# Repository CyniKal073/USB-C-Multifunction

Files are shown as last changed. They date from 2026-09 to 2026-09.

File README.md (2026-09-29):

# USB-C Multifunction

一款面向消费电子的 **USB Type-C 多功能扩展设备**：在单根 Type-C 连接下同时实现 USB 扩展、PD 快充透传、USB Audio 与外设线控交互，解决移动设备取消 3.5mm 耳机孔后「边充电边使用有线耳机」的问题。

> *A USB Type-C multifunction dock featuring USB 2.0 hub expansion, PD pass-through charging, a built-in USB audio codec, and MCU-based headset remote emulation.*

本项目为个人独立完成的完整硬件项目，涵盖系统方案设计与器件选型、4 层 PCB 设计、外壳结构设计与裸机固件开发。

设计初衷很直接：让那些喜欢同时插着一堆外设的人，可以边充电边用。

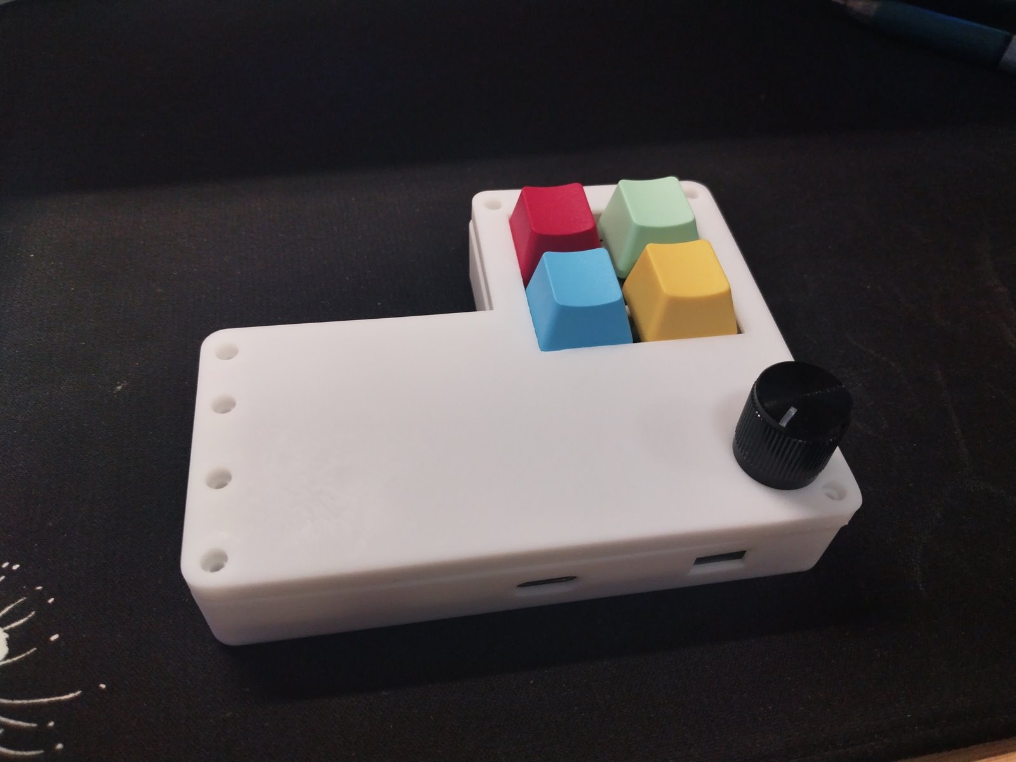
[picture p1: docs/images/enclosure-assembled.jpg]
成品实物


*成品外观：4 个可编程按键 + EC11 旋钮，外壳为自建 3D 模型打印件。*

---

## 目录

- [功能特性](#功能特性)
- [系统架构](#系统架构)
- [实测指标](#实测指标)
- [硬件设计](#硬件设计)
- [结构设计](#结构设计)
- [设计演进与实物](#设计演进与实物)
- [固件](#固件)
- [仓库结构](#仓库结构)
- [待办与已知问题](#待办与已知问题)
- [致谢与许可](#致谢与许可)

---

## 功能特性

| 功能 | 说明 |
| --- | --- |
| **USB 扩展** | 基于 CH334P 四口 USB 2.0 Hub，下行提供 2× USB-A 与 2× Type-C 接口，支持 480Mbps 高速模式 |
| **PD 快充透传** | 由 MCU 完成 Type-C CC 检测与 PD Sink 逻辑，扣除板载约 5W 供电后，最大可透传 95W 快充 |
| **USB Audio** | 板载 ATE700Q 音频编解码芯片，支持 44.1kHz / 96kHz 采样，可直接驱动 16–32Ω 耳机 |
| **线控交互** | 通过模拟开关与 MCU 时序控制模拟 CTIA 标准线控协议，以阻抗脉冲方式注入按键事件，扩展声卡线控功能 |
| **正反插识别** | Type-C CC 检测实现设备端正反插识别，并动态切换外围信号通道 |
| **可编程控制** | 4 个可编程按键与 EC11 旋转编码器，由 CH32X035F8U6 裸机固件驱动，实现 USB HID 复合设备与事件管理 |

## 系统架构

```mermaid
flowchart LR
    HOST["手机 / 主机<br/>Type-C 上行"] --> HUB["CH334P<br/>USB 2.0 Hub<br/>480Mbps<br/>CH227P"]
    HUB --> A["2× USB-A"]
    HUB --> C["2× Type-C"]
    HUB --> CODEC["ATE700Q<br/>USB Audio Codec"]
    CODEC --> JACK["3.5mm 耳机座 CN1"]
    MCU["CH32X035F8U6<br/>RISC-V MCU"] --> SW["TS3A5017<br/>模拟开关"]
    SW --> JACK
    MCU --> ENC["EC11 旋转编码器"]
    MCU --> KEY["按键矩阵"]
    MCU --> CC["Type-C CC 检测 / PD Sink"]
```

> 上图为简化示意，完整连接关系以 [`hardware/schematic`](hardware/schematic) 中的原理图为准。

## 实测指标

| 项目 | 结果 |
| --- | --- |
| USB 集线器速率 | 480Mbps 高速模式 |
| 快充功率 | 扣除板载约 5W 供电后，设计最大透传 95W |
| PD 实测 | 用 20W 充电器验证 PD 透传通路：协议 PD3.0 握手成功，协商到 15W 档位（12V / 1.25A），实测 14.12W |
| 音频采样率 | 44.1kHz / 96kHz |
| 耳机驱动能力 | 16–32Ω |

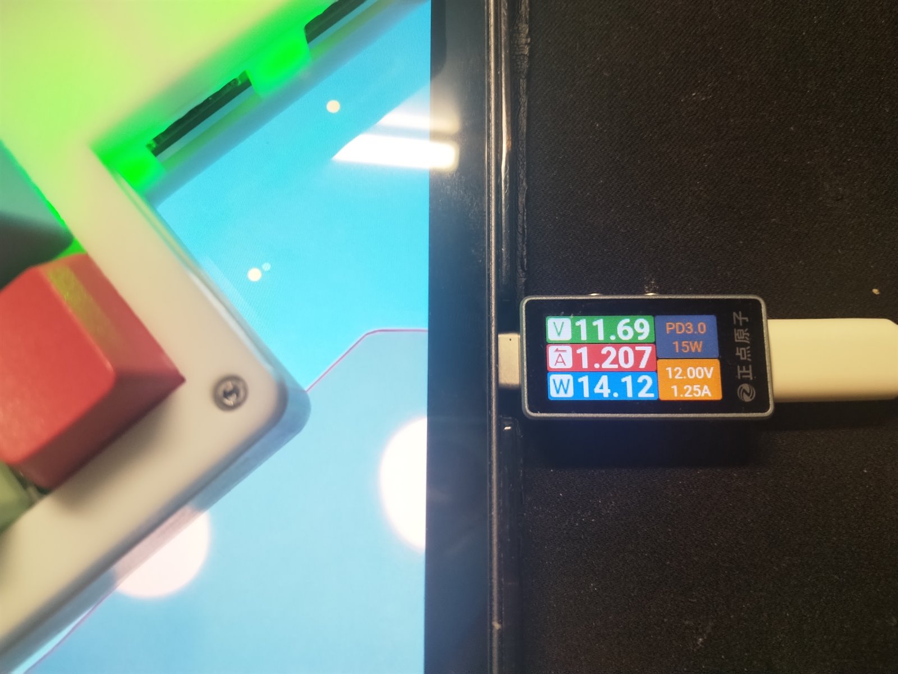
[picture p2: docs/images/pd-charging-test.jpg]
PD 快充实测


*以平板为受电端的 PD 实测：协议 PD3.0，电压 11.69V、电流 1.207A，功率 14.12W。这里之所以只看到 15W 档，是因为手上的充电器最大输出只有 20W——该测试的目的不是验证功率上限，而是确认板上约 5W 的自耗确实是从透传功率里扣除的。*

## 硬件设计

4 层板设计，重点处理 USB 2.0 差分信号阻抗与等长、电源平面规划以及高速信号回流路径；针对 USB、电源与模拟音频接口分别设计 ESD 防护与可靠性措施。

### 核心器件

| 位号 | 型号 | 厂商 | 作用 |
| --- | --- | --- | --- |
| U1 | CH32X035F8U6 | 南京沁恒 (WCH) | 主控 MCU，RISC-V 内核，负责 CC 检测、线控时序与 HID 通信 |
| U2 | CH334P | 南京沁恒 (WCH) | USB 2.0 四口 Hub 控制器 |
| U10 | CH227P | 南京沁恒 (WCH) | PD 快充协议芯片，与 CH334P 共同构成 HUB + PD 方案 |
| U29 | ATE700Q | — | USB 音频编解码（板载声卡） |
| U36 | TS3A5017DR | TI | 4:1 模拟开关，用于线控阻抗脉冲注入 |
| U11 / U35 | CH443K | 南京沁恒 (WCH) | 模拟开关，用于外围信号通道切换 |
| SW5 | EC11E15244G1 | ALPSALPINE | 旋转编码器（带按压） |
| CN1 | ST-0337D00-071-1A2H | G-Switch | 3.5mm 音频座 |
| D2/D7/D11/D13 | USBLC6-2SC6 | ST | USB 差分线 ESD 防护 |
| D10/D14/D15/D16 | RClamp0524PATCT | SEMTECH | 高速信号 ESD 防护 |

整个方案围绕 CH334P + CH227P 展开，供电通路同时做过流、过压与静电防护。

- **可编辑工程**：立创EDA 专业版（EasyEDA Pro）的原理图与 PCB 工程文件见 [`hardware/eda`](hardware/eda)，导入后可直接修改。
- **物料清单**：见 [`hardware/bom`](hardware/bom)，含原版 xlsx 与文本版 `BOM_*_2026-09-30.tsv`（UTF-8、Tab 分隔——位号列本身含逗号，用 Tab 分隔可以避免转义问题），文本版便于在 GitHub 上直接预览表格以及做版本对比。

### 制板与焊接注意事项

- 线对板针座（卧贴封装）的原始焊盘偏小，手工焊接时容易连锡。打板前建议手动把这两个焊盘向外加大，可明显降低焊接难度。

## 结构设计

`mechanical/` 下为 EasyEDA Pro 导出的外壳 3D 模型（ASCII STL），上下盖按装配位置导出：

| 文件 | 部件 | Z 范围 |
| --- | --- | --- |
| `enclosure-bottom.stl` | 下盖 | 0 – 15mm |
| `enclosure-top.stl` | 上盖 | 15 – 20mm |

整体外形尺寸约 **103.8 × 84.7 × 20mm**。

## 设计演进与实物

最终方案不是一次成型的。从选型验证到集成，前后经历了几个阶段，各阶段的原理图与制板文件都保留在 [`hardware/legacy`](hardware/legacy) 下，实物照片放在 [`docs/images`](docs/images)。

| 阶段 | 内容 | 记录位置 |
| --- | --- | --- |
| ① 声卡方案验证 | 基于 HS-100B 的 USB 声卡，含外壳 | `hardware/legacy/usb-soundcard-hs100b/` |
| ② 声卡方案更换 | 改用 ATE700Q，体积大幅缩小 | `hardware/legacy/usb-soundcard-ate700q/` |
| ③ 主体功能验证 | 4 口 HUB + PD 快充主板（原理图 v1） | `hardware/legacy/hub-v1/` |
| ④ 系统集成 | HUB + PD + 声卡 + MCU 线控合成单板 | 本仓库 `hardware/` `mechanical/` `firmware/` |

### 实物照片

最终版（阶段 ④）：

| 照片 | 说明 |
| --- | --- |
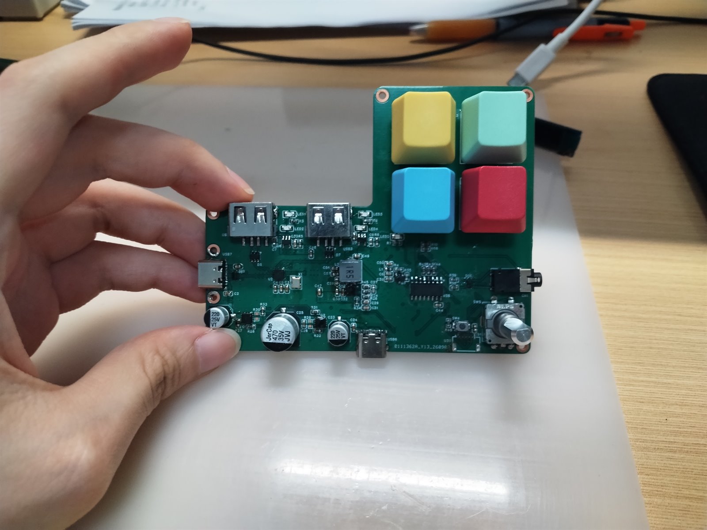
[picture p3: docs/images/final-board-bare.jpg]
最终版裸板
|  | 焊接完成的主板：4 个可编程按键、EC11 旋钮、USB-A、Type-C 与 3.5mm 耳机座 |
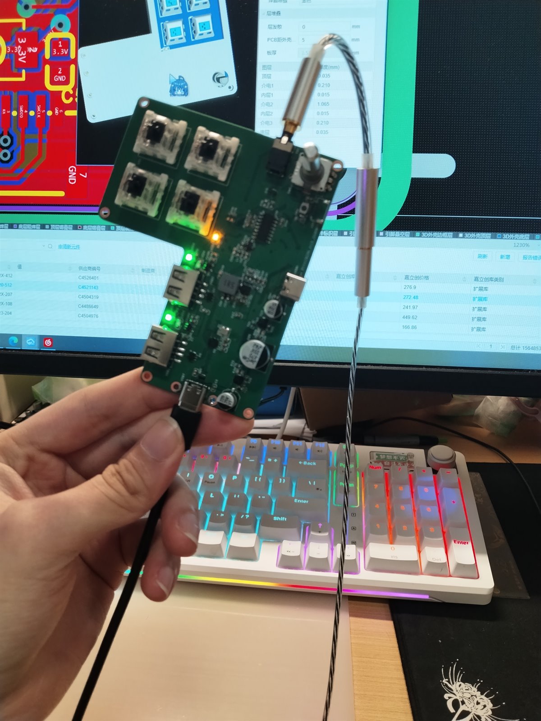
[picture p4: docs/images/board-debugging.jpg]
上电调试
|  | 上电调试：板载指示灯状态与逻辑分析仪抓取 |
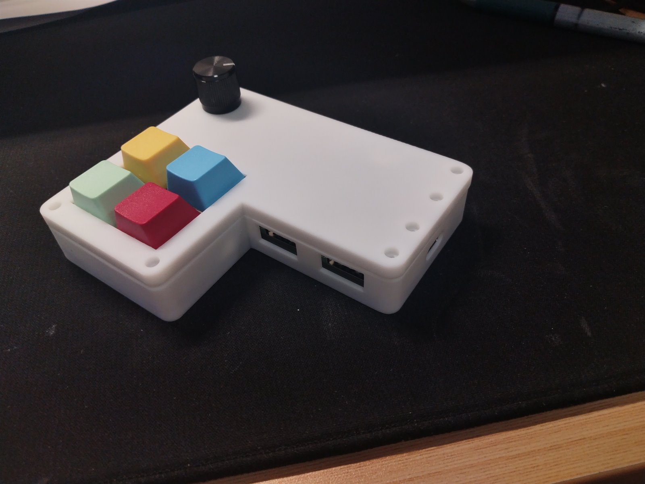
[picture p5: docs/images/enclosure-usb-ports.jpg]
侧面 USB 口
|  | 装壳后侧面的 USB 扩展口 |
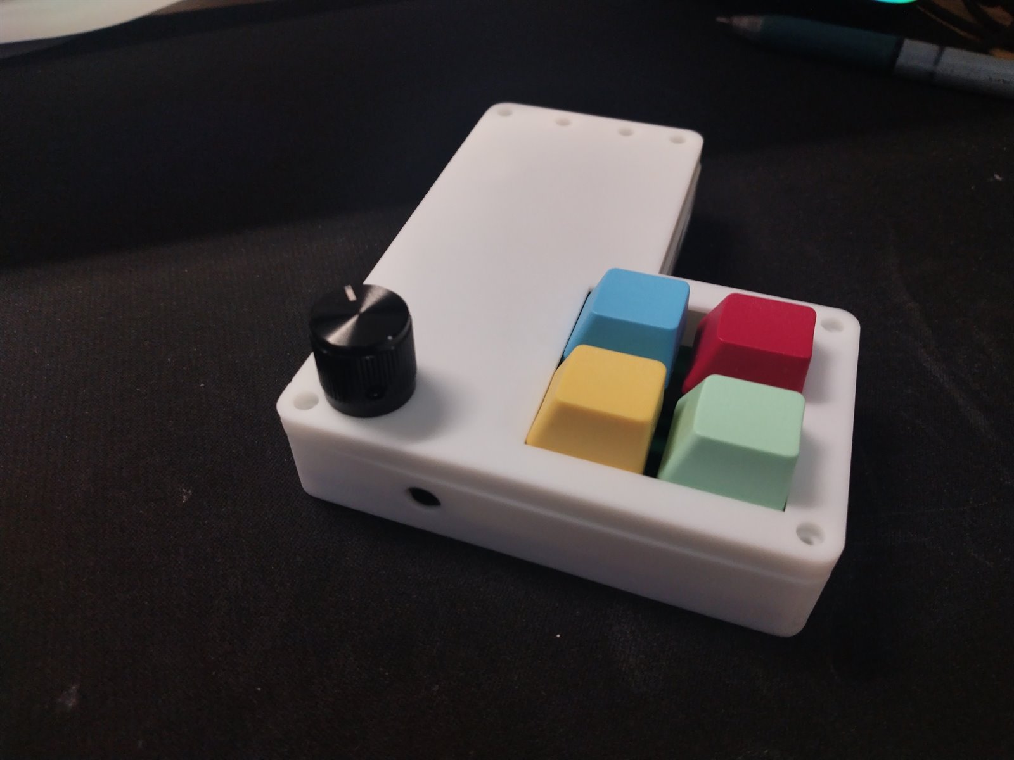
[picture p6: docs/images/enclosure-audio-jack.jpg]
侧面音频座
|  | 装壳后侧面的 3.5mm 音频座开孔 |

早期版本（阶段 ①②③）的照片见 [`docs/images`](docs/images)：[4 口 HUB + PD 主板 v1](docs/images/hub-pd-mainboard-v1.jpg)、[HS-100B 声卡装壳成品](docs/images/hs100b-usb-soundcard-enclosed.jpg)、[两块声卡对照](docs/images/hs100b-and-ate700q-boards.jpg)、[ATE700Q 声卡小板](docs/images/ate700q-usb-soundcard-board.jpg)、[系统联调](docs/images/system-integration-test.jpg)、[X033-NanoPlus 键盘外设](docs/images/x033-nanoplus-keyboard.jpg)。

## 固件

### 开发环境

| 项目 | 说明 |
| --- | --- |
| MCU | CH32X035F8U6（RISC-V，62KB Flash / 20KB SRAM） |
| IDE | MounRiver Studio（内置 RISC-V GCC 工具链，工程基于 Eclipse CDT） |
| 调试器 | WCH-Link |
| 系统时钟 | 48MHz（HSI） |

### 编译与烧录

1. 使用 MounRiver Studio 打开 `firmware/CH32X035F8U6` 目录（含 `.project` / `.cproject`，可直接导入）。
2. 编译后固件输出为 `obj/CH32X035F8U6.hex`。
3. 连接 WCH-Link，烧录配置已保存在 `.template` 中：起始地址 `0x08000000`，擦除 → 编程 → 校验 → 复位。

> `obj/` 为编译产物，已通过 `.gitignore` 排除，首次编译时由 IDE 自动生成。
> 所有源码文件使用 **UTF-8** 编码，若中文注释显示异常请在 IDE 中将工程编码设置为 UTF-8。

### 主要模块

| 文件 | 功能 |
| --- | --- |
| `User/main.c` | 主循环、TIM1 1ms 系统节拍、EC11 处理、模拟开关通道控制 |
| `User/PD_Process.c` | Type-C CC 电平检测与 PD Sink 状态机 |
| `User/usbd_compostie_km.c` | USB HID 复合设备按键扫描与数据上报 |
| `User/usb_desc.c` | USB 描述符定义 |
| `User/ch32x035_usbfs_device.c` | USBFS 设备底层驱动 |
| `Core/` `Peripheral/` `Startup/` `Debug/` | 沁恒官方 CH32X035 SDK（外设驱动、内核、启动文件、调试打印） |

### 关键实现

- **非阻塞状态机**：以 1ms 定时器中断为时基，EC11 旋转编码器采用状态机 + 计数消抖，避免在主循环中阻塞等待。
- **线控协议模拟**：按 CTIA 标准，通过 TS3A5017 切换不同阻抗通道（如 240Ω / 470Ω）产生阻抗脉冲，模拟音量键与播放/暂停按键。
- **PD / CC 检测**：CC 电平轮询检测配合 PB12 通道翻转，实现正反插识别与外围信号切换。

## 仓库结构

```
USB-C-Multifunction
├── hardware/                          硬件设计
│   ├── schematic/                     最终版原理图（PDF）
│   ├── eda/                           立创EDA 专业版工程（可编辑源文件）
│   ├── pcb/                           最终版 Gerber 制板文件
│   ├── bom/                           物料清单（xlsx + tsv）
│   └── legacy/                        历史版本，保留原始记录
│       ├── hub-v1/                    4 口 HUB + PD 主板 v1
│       ├── usb-soundcard-ate700q/     ATE700Q 声卡方案
│       └── usb-soundcard-hs100b/      HS-100B 声卡方案
├── mechanical/                        外壳 3D 模型（STL）
├── firmware/                          嵌入式固件
│   └── CH32X035F8U6/                  MounRiver Studio 工程
├── X033-NanoPlus/                     子项目：CH32X033F8P6 键盘 HID 外设
└── docs/                              说明文档与实物照片
    ├── project-description.txt
    ├── notes-2026-09.txt
    └── images/
```

> `hardware/legacy/` 与 `X033-NanoPlus/` 是开发过程中留下的早期设计与衍生子项目，原样保留以便追溯，代码与图纸未做清理。对外代表本项目的最终成果以 `hardware/` `mechanical/` `firmware/` 三个目录为准。

## 待办与已知问题

### 已知问题：上行口正反插识别不稳定

上行 Type-C 的正反插识别尚未完全稳定——两种插入方向中总有一个方向异常，另一个方向功能正常：

- **接入手机 / 平板等移动设备时**：某一个固定方向无法识别到 PD 快充，其余功能（USB 扩展、音频）均正常。
- **接入电脑时**：某一个固定方向无法识别到板载键盘。但用 USB 设备树查看器可以确认电脑已正确识别到该 HID 设备，只是 Wireshark 抓不到按键按下时上报的数据。

可能的成因有两个方向，都还没有深入验证：

- **CC 检测与通道切换的时序**：当前固件通过 PB12 在两个 CC 通道间翻转，切换窗口与对端设备的 CC 采样时刻可能对不齐。
- **MCU 未外接晶振**：主控只用了内部 RC 振荡器（HSI 48MHz），时钟精度不如外部晶振，可能压缩了 USB 通信与 CC 检测的时序余量。HUB 芯片 CH334P 的外部晶振是齐全的，因此 USB 扩展功能不受影响，异常只出现在上行口相关的部分。

### 待办

- [ ] `hardware/legacy/` 下各历史版本仍然只有 Gerber，没有对应的可编辑工程
- [ ] 补充外壳 STEP 或原始建模文件
- [ ] 定位并修复上行口正反插识别问题
- [ ] 补充音频采样率等其余测试项的截图
- [ ] 补充装配说明与接线示意

## 致谢与许可

- MCU 外设驱动、内核与启动文件基于南京沁恒（WCH）官方 CH32X035 SDK（PeripheralVersion 1.9），相关文件保留原始版权声明。
- 其余部分由本人独立完成，采用 [MIT License](LICENSE) 开源。

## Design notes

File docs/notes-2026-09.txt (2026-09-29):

ps：嘉立创EDA给的线对板针座的卧贴的两个焊盘太小了，我老是把它焊糊（笑），建议还是手动给它们拉的大一点，方便焊接
目前使用问题：上行正反插仍然有识别问题，主要出现在：当接入设备为手机、平板等移动设备时，某一确定的方向无法识别到PD快充，但是其他功能均能正常使用；当接入设备为电脑时，某一确定的方向无法识别到板载键盘，但是我用USB设备树查看器能够看到电脑正确识别到该HID设备，不过使用Wireshark抓包还是捕获不到按下时的数据。

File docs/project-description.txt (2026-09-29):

● 项目背景：出于个人兴趣以及针对部分移动设备取消3.5mm耳机接口以及接口扩展需求，设计一款集USB扩展、PD快充透传、USB Audio及可编程控制于一体的Type-C多功能扩展设备，实现边充电边使用有线耳机及多外设连接。
● 项目目标：独立完成USB Type-C多功能扩展终端硬件架构设计，实现USB扩展、音频输出及线控交互功能。基于CH334P USB Hub控制器、ATE700Q音频编解码芯片、CH32X035F8U6 MCU等器件完成系统方案设计与器件选型。
● 工作内容：
1、独立设计4层PCB，完成USB 2.0差分信号布线、电源平面规划及高速信号回流路径优化；针对USB、电源及模拟音频接口设计ESD防护与可靠性措施。
2、 基于CH32X035F8U6裸机开发环境完成USB HID设备功能开发，优化官方USB协议栈，实现自定义键盘数据通信；结合USB抓包分析定位并解决协议交互异常及底层资源冲突问题。
3、 设计Type-C CC检测及状态切换逻辑，实现设备端正反插识别与外围信号动态切换；基于定时器中断设计非阻塞状态机，实现EC11旋转编码器消抖及事件管理。
4、 基于模拟开关与MCU时序控制实现CTIA标准音频线控协议模拟，通过阻抗脉冲方式完成按键事件注入，实现声卡线控功能扩展。
● 项目成果：经测试 USB集线器支持480Mbps高速模式，PD经5W板上供电扣除后快充最大95W，板载声卡ATE700Q支持44.1k/96kHz采样，可直接驱动16-32Ω耳机。

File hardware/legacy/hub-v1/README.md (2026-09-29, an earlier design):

This device is based on CH334P (for hub function) and CH227P (for PD fast charging) with overcurrent protection, overvoltage protection and electrostatic protection.

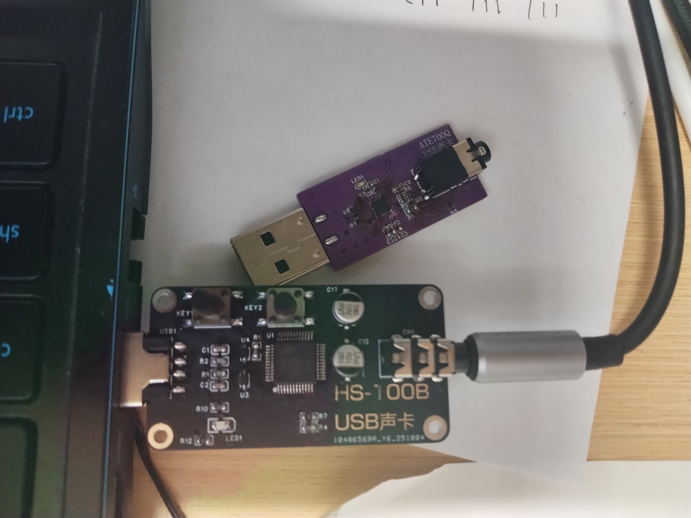
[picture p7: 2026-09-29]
docs/images/hs100b-and-ate700q-boards.jpg

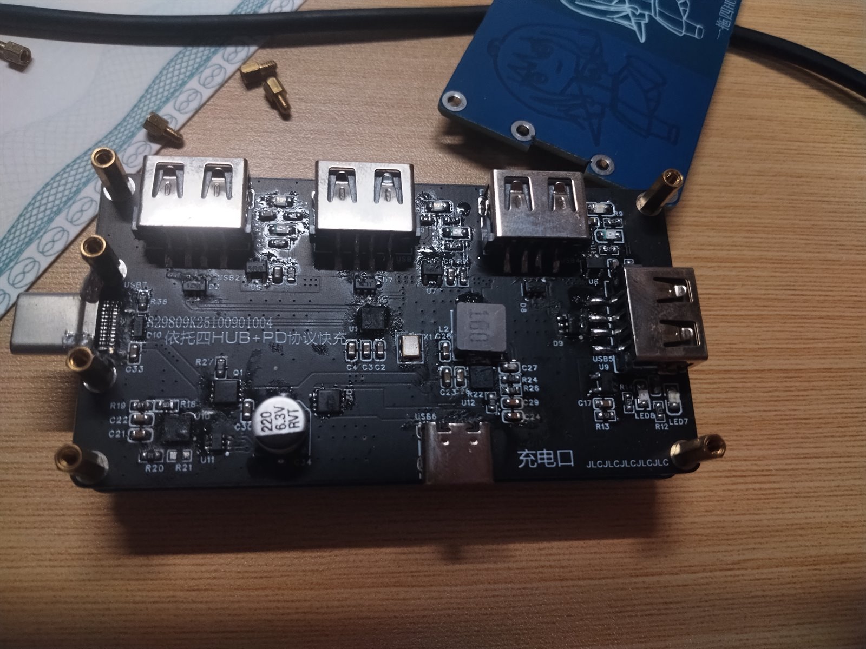
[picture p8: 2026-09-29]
docs/images/hub-pd-mainboard-v1.jpg

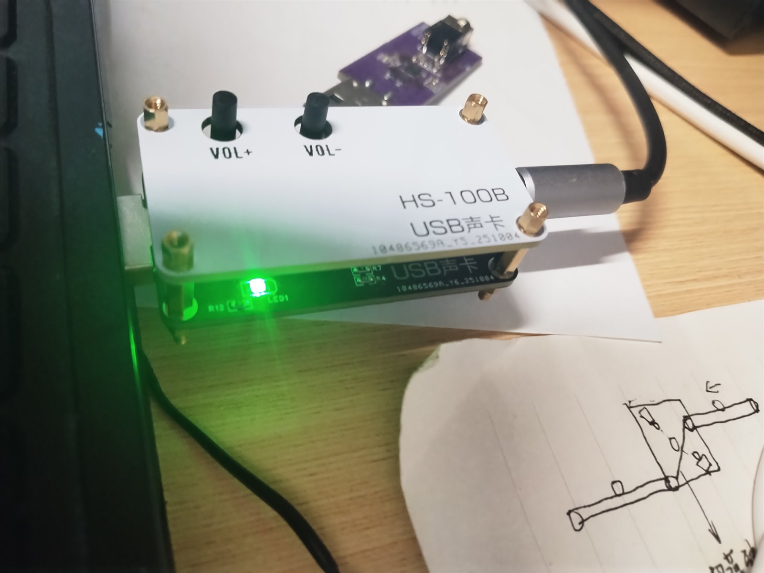
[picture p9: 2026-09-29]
docs/images/hs100b-usb-soundcard-enclosed.jpg

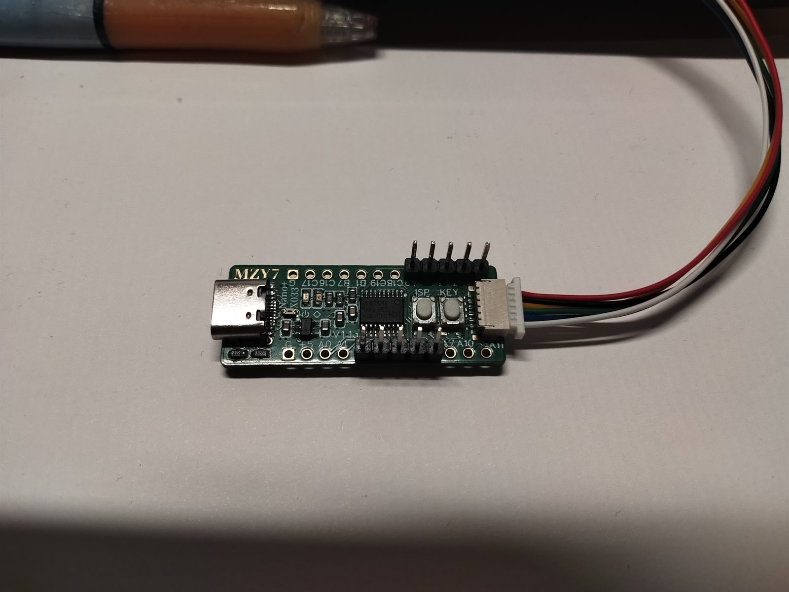
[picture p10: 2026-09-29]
docs/images/x033-nanoplus-keyboard.jpg

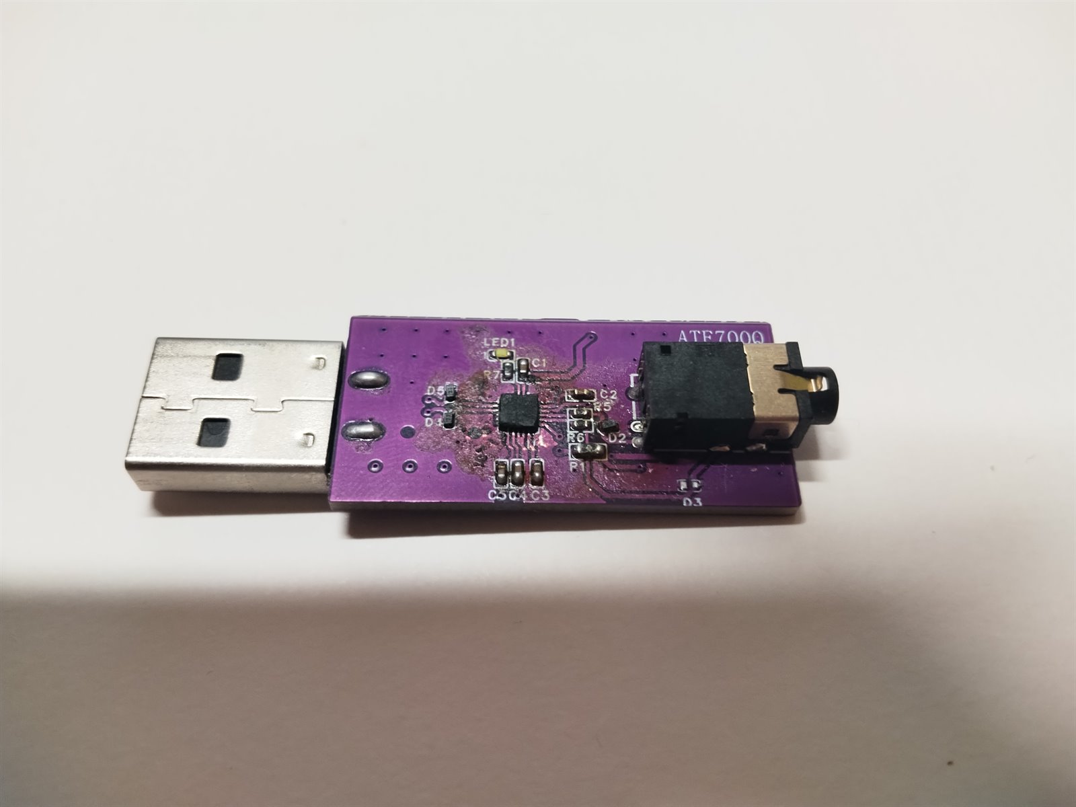
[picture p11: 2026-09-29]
docs/images/ate700q-usb-soundcard-board.jpg

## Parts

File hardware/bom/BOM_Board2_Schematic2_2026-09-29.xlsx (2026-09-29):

No. | Quantity | Comment | Designator | Footprint | Value | Manufacturer Part | Manufacturer | Supplier Part | Supplier
1 | 2 | 220uF | C1,C23 | CAP-SMD_BD6.3-L6.6-W6.6-LS7.3-FD-H7.7 | 220uF | JVJ25V220M6x8 | JIERR(捷而瑞) | C46550404 | LCSC
2 | 5 | 1uF | C2,C24,C26,C42,C43 | C0603 | 1uF
3 | 6 | 10uF | C3,C7,C9,C10,C30,C33 | C0603 | 10uF | CL10A106KP8NNNC | SAMSUNG(三星) | C19702 | LCSC
4 | 3 | 1uF | C4,C22,C32 | C0603 | 1uF | CL10A105KB8NNNC | SAMSUNG(三星) | C15849 | LCSC
5 | 3 | 100nF | C5,C21,C31 | C0603 | 100nF | CGA0603X7R104K500JT | HRE(芯声) | C6119867 | LCSC
6 | 2 | 10uF | C6,C39 | C0603 | 10uF | CL10A106KO8NQNC | SAMSUNG(三星) | C962136 | LCSC
7 | 1 | 470uF | C25 | CAP-SMD_BD10.0-L10.3-W10.3-LS11.0 | 470uF | JVJ35V470M10x10 | JIERR(捷而瑞) | C46550413 | LCSC
8 | 1 | 220pF | C27 | C0603 | 220pF | CC0603JRNPO9BN221 | YAGEO(国巨) | C106210 | LCSC
9 | 3 | 22uF | C28,C56,C57 | C0603 | 22uF | HGC0603R5226M100NTHJ | Chinocera(华瓷) | C7432770 | LCSC
10 | 1 | 2.2uF | C29 | C0603 | 2.2uF | CL10A225KO8NNNC | SAMSUNG(三星) | C23630 | LCSC
11 | 5 | 1uF | C34,C35,C36,C37,C38 | C0603 | 1uF | CL10A105KO8NNNC | SAMSUNG(三星) | C1592 | LCSC
12 | 1 | 4.7uF | C40 | C0603 | 4.7uF
13 | 13 | 100nF | C41,C44,C45,C46,C47,C48,C49,C50,C51,C52,C53,C54,C55 | C0603 | 100nF
14 | 1 | ST-0337D00-071-1A2H | CN1 | AUDIO-TH_ST-0337D00-071-1A2H |  | ST-0337D00-071-1A2H | G-Switch(品赞) | C2829972 | LCSC
15 | 4 | USBLC6-2SC6 | D2,D7,D11,D13 | SOT-23-6_L2.9-W1.6-P0.95-LS2.8-BL |  | USBLC6-2SC6 | ST(意法半导体) | C7519 | LCSC
16 | 4 | RClamp0524PATCT | D10,D14,D15,D16 | SLP2510P8_L2.5-W1.0-P0.50-BL |  | RClamp0524PATCT | SEMTECH | C40960 | LCSC
17 | 1 | MF-FSMF050X-2 | F1 | F0603 |  | MF-FSMF050X-2 | BOURNS | C210357 | LCSC
18 | 1 | BLM18PG221SN1D | L1 | L0603 |  | BLM18PG221SN1D | muRata(村田) | C80165 | LCSC
19 | 1 | 1.5uH | L2 | IND-SMD_L7.0-W6.6 | 1.5uH | MWSA0603S-1R5MT | Sunlord(顺络) | C408444 | LCSC
20 | 1 | ME6211C33M5G-N | LDO1 | SOT-23-5_L3.0-W1.7-P0.95-LS2.8-BL |  | ME6211C33M5G-N | MICRONE(南京微盟) | C82942 | LCSC
21 | 3 | ORH-G35A | LED1,LED3,LED5 | LED0805-R-RD |  | ORH-G35A | Orient(奥伦德) | C205442 | LCSC
22 | 3 | XL-2012SURC | LED2,LED4,LED6 | LED0805-RD_RED |  | XL-2012SURC | XINGLIGHT(成兴光) | C965812 | LCSC
23 | 2 | NCE30P20Q | Q1,Q2 | PDFN3333-8_L3.1-W3.2-P0.65-LS3.4-BL |  | NCE30P20Q | NCE(无锡新洁能) | C502778 | LCSC
24 | 1 | AO3401A | Q3 | SOT-23_L2.9-W1.3-P1.90-LS2.4-BR |  | AO3401A | AOS | C15127 | LCSC
25 | 1 | 0Ω | R1 | R0603 | 0Ω | 0603WAF0000T5E | UNI-ROYAL(厚声) | C21189 | LCSC
26 | 4 | 4.7kΩ | R3,R5,R6,R8 | R0603 | 4.7kΩ | 0603WAF4701T5E | UNI-ROYAL(厚声) | C23162 | LCSC
27 | 2 | 100kΩ | R4,R20 | R0603 | 100kΩ | FRC0603F1003TS | FOJAN(富捷) | C2906980 | LCSC
28 | 1 | 470Ω | R7 | R0603 | 470Ω | FRC0603J471 TS | FOJAN(富捷) | C2907172 | LCSC
29 | 2 | 2.2k | R10,R36 | R0603 | 2.2k
30 | 2 | 5.1kΩ | R15,R16 | R0603 | 5.1kΩ | 0603WAF5101T5E | UNI-ROYAL(厚声) | C23186 | LCSC
31 | 1 | 10Ω | R19 | R0603 | 10Ω | 0603WAF100JT5E | UNI-ROYAL(厚声) | C22859 | LCSC
32 | 3 | NC | R21,R29,R30 | R0603 | NC
33 | 1 | 100Ω | R22 | R0603 | 100Ω | 0603WAF1000T5E | UNI-ROYAL(厚声) | C22775 | LCSC
34 | 6 | 100kΩ | R24,R27,R28,R31,R32,R34 | R0603 | 100kΩ | 0603WAF1003T5E | UNI-ROYAL(厚声) | C25803 | LCSC
35 | 1 | 13.7k | R26 | R0603 | 13.7k | 0603WAF1802T5E | UNI-ROYAL(厚声) |  | LCSC
36 | 1 | 1kΩ | R33 | R0603 | 1kΩ | 0603WAF1001T5E | UNI-ROYAL(厚声) | C21190 | LCSC
37 | 1 | 10kΩ | R35 | R0603 | 10kΩ | FRC0603J103 TS | FOJAN(富捷) | C2930027 | LCSC
38 | 2 | 33Ω | R38,R39 | R0603 | 33Ω | 0603WAF330JT5E | UNI-ROYAL(厚声) | C23140 | LCSC
39 | 1 | 4.7k | R40 | R0603 | 4.7k
40 | 3 | 1k | R41,R44,R45 | R0603 | 1k
41 | 1 | 1xx | R42 | R0603 | 1xx
42 | 1 | 470 | R43 | R0603 | 470
43 | 1 | TS-1088-AR02016 | SW4 | SW-SMD_L3.9-W3.0-P4.45 |  | TS-1088-AR02016 | XUNPU(讯普) | C720477 | LCSC
44 | 1 | EC11E15244G1 | SW5 | SW-TH_EC11E15244G1 |  | EC11E15244G1 | ALPSALPINE(阿尔卑斯阿尔派) | C370970 | LCSC
45 | 1 | CH32X035F8U6 | U1 | WQFN-20_L3.0-W3.0-P0.40-TL-EP1.7 |  | CH32X035F8U6 | WCH(南京沁恒) | C42442062 | LCSC
46 | 1 | CH334P | U2 | QFN-16_L3.0-W3.0-P0.50-BL-EP1.7 |  | CH334P | WCH(南京沁恒) | C5373042 | LCSC
47 | 2 | SY6288CAAC | U6,U7 | SOT-23-5_L3.0-W1.7-P0.95-LS2.8-BR |  | SY6288CAAC | Silergy(矽力杰) | C111830 | LCSC
48 | 1 | CH227P | U10 | TQFN-16_L3.0-W3.0-P0.50-BL-EP1.7 |  | CH227P |  | C17179553 | LCSC
49 | 2 | CH443K | U11,U35 | SC70-6_L2.1-W1.3-P0.65-LS2.3-BL |  | CH443K | WCH(南京沁恒) | C125185 | LCSC
50 | 1 | SY8368QNC | U12 | QFN-10_L3.0-W3.0-P0.45-TL_SILERGY |  | SY8368QNC | Silergy(矽力杰) | C125897 | LCSC
51 | 2 | 150uF | U14,U28 | CAP-SMD_L7.3-W4.3-R-RD | 150uF | EEFCX0J151XR | PANASONIC(松下) | C542158 | LCSC
52 | 1 | ATE700Q | U29 | QFN-20_L3.0-W3.0-P0.40-BL-EP1.7 |  | ATE700Q |  | C9900091727 | LCSC
53 | 1 | ZX-SH1.0-6PWT | U30 | CONN-SMD_6P-P1.00_MEGASTAR_ZX-SH1.0-6PWT |  | ZX-SH1.0-6PWT | Megastar(兆星) | C7430448 | LCSC
54 | 4 | CPG151101D13 | U31,U32,U33,U34 | KEY-TH_CPG151101D21X |  | CPG151101D13 | HanElectricity(瀚源) | C49234235 | LCSC
55 | 1 | TS3A5017DR | U36 | SOIC-16_L9.9-W3.9-P1.27-LS6.0-BL |  | TS3A5017DR | TI(德州仪器) | C181505 | LCSC
56 | 2 | 10.0 QHHTZB6.3 | USB2,USB3 | USB-A-TH_10.0QHHTZB6.3 |  | 10.0 QHHTZB6.3 | SHOU HAN(首韩) | C668591 | LCSC
57 | 2 | TYPE-C 16PIN 2MD(073) | USB6,USB7 | USB-C-SMD_TYPE-C-6PIN-2MD-073 |  | TYPE-C 16PIN 2MD(073) | SHOU HAN(首韩) | C2765186 | LCSC
58 | 1 | 12MHz | X1 | CRYSTAL-SMD_4P-L3.2-W2.5-BL | 12MHz | X322512MSB4SI | YXC(扬兴晶振) | C9002 | LCSC

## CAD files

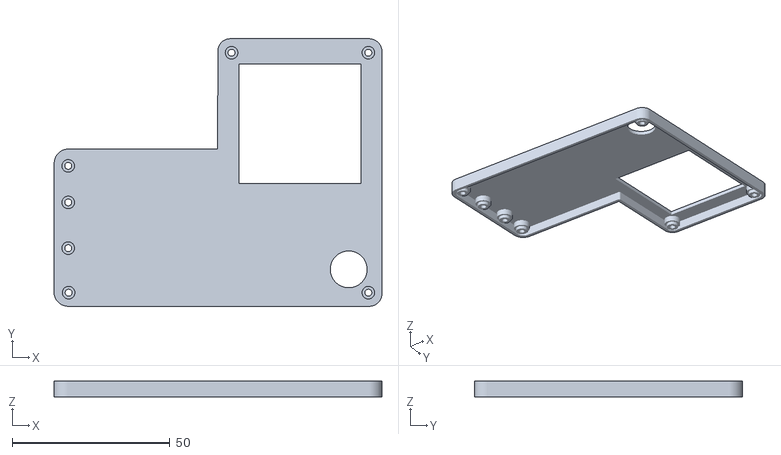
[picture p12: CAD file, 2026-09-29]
mechanical/enclosure-top.stl
103.8 x 84.7 x 5.00

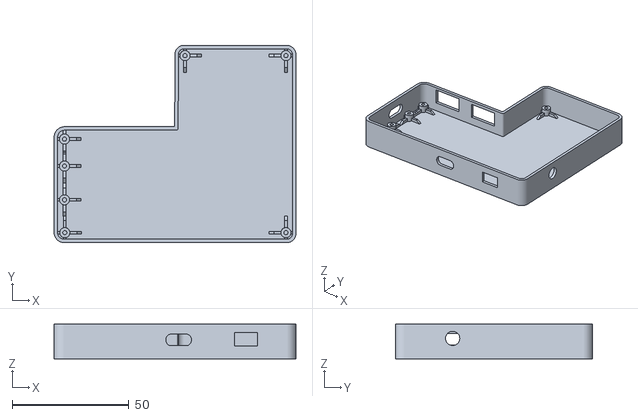
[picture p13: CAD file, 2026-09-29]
mechanical/enclosure-bottom.stl
103.8 x 84.7 x 15.0

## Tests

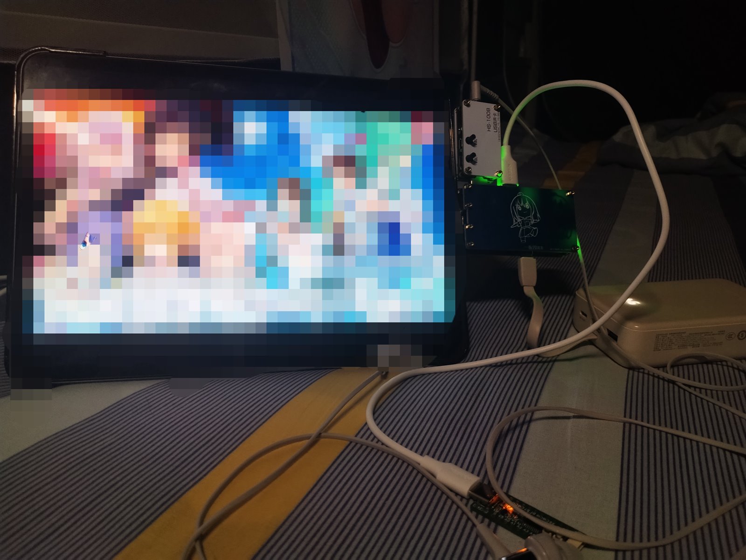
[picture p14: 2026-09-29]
docs/images/system-integration-test.jpg

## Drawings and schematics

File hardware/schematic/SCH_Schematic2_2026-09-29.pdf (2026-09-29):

# ESD防护

## 防倒灌开关

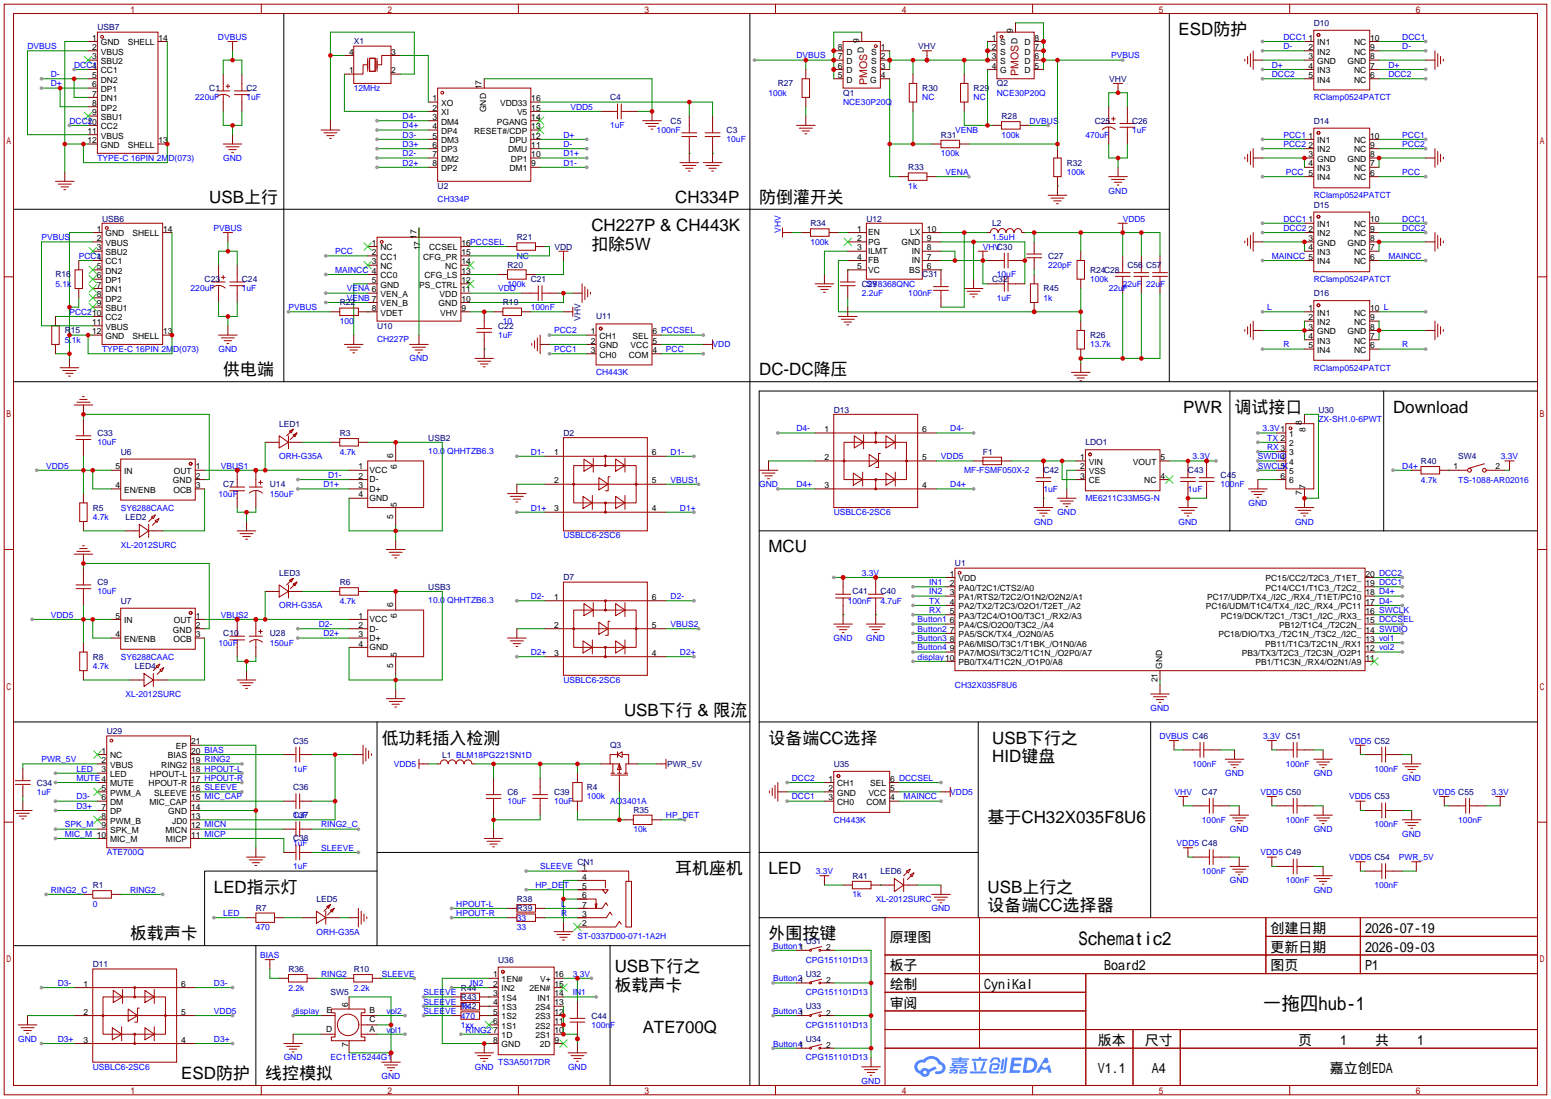
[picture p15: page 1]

GND 10 VDD 11 PS_CTRL 12 CFG_LS 13 NC 14 CFG_PR 15 CCSEL 16 17 17

更新日期 | 2026-09-03

板子 | Board2 | 图页 | P1
绘制 | CyniKal | 一拖四hub-1
审阅

V1.1 | A4 | 嘉立创EDA

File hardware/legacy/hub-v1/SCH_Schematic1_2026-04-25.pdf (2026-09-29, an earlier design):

USB上行+HUB芯片 | USB下行

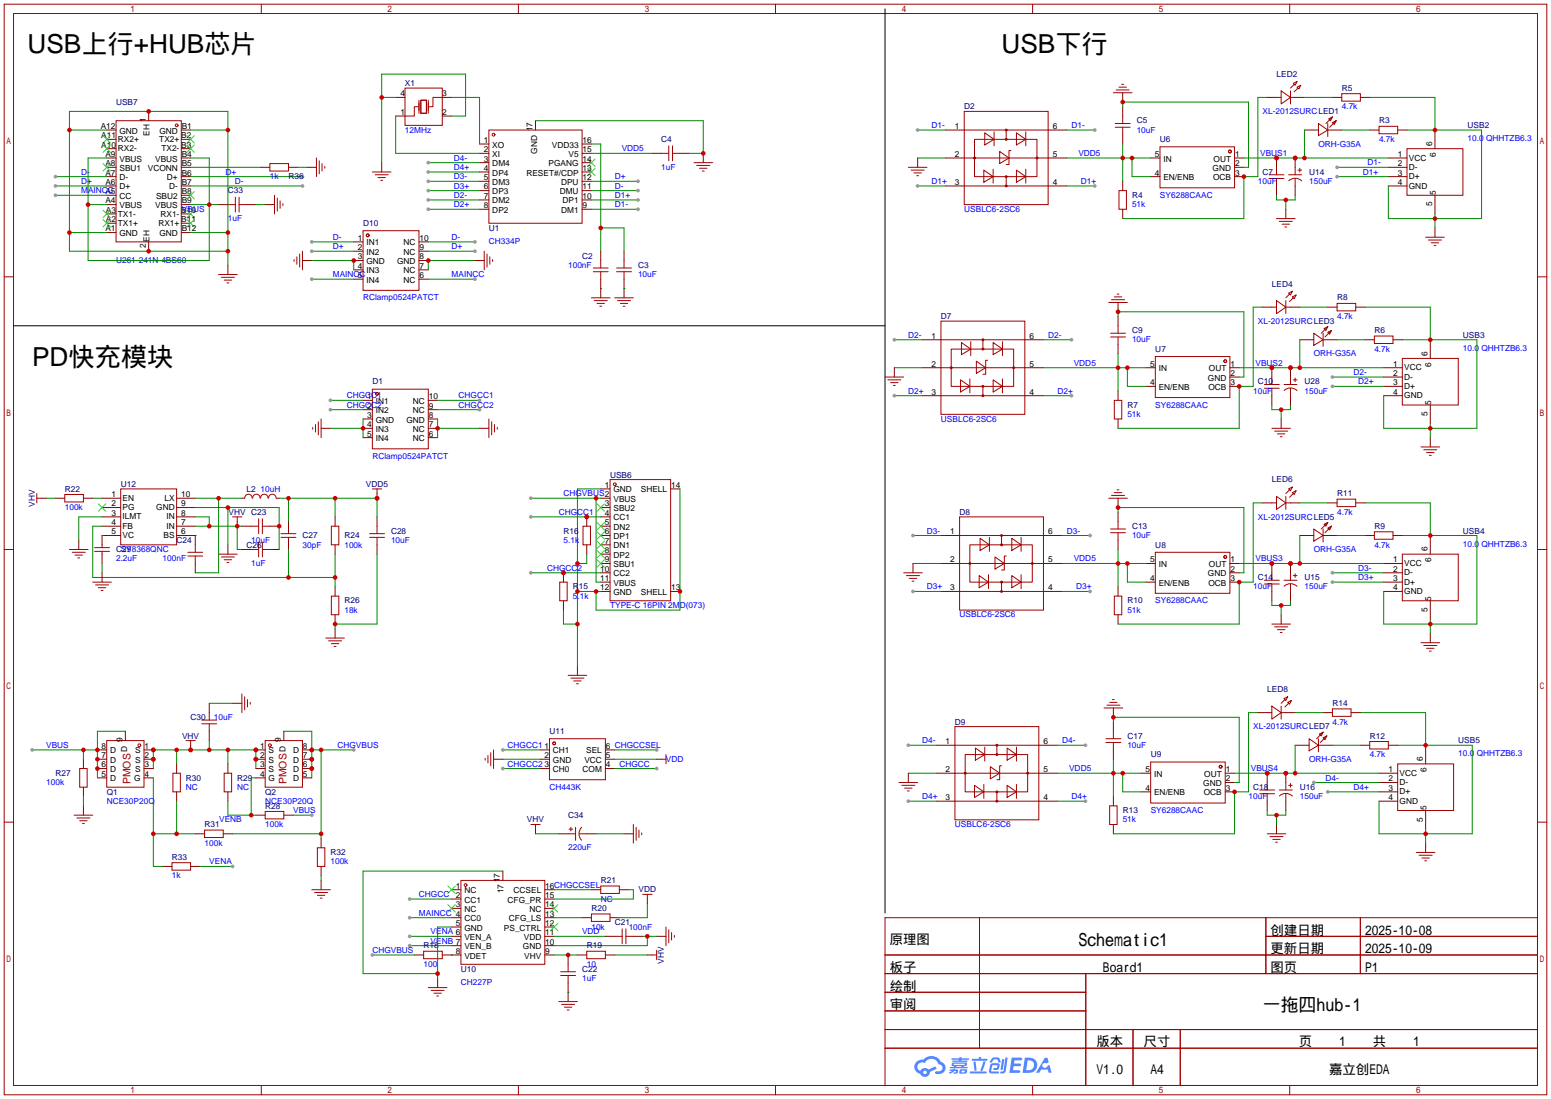
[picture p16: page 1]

GND 10 VDD 11 PS_CTRL 12 CFG_LS 13 NC 14 CFG_PR 15 CCSEL 16

原理图 | Schematic1 | 创建日期 | 2025-10-08

更新日期 | 2025-10-09

板子 | Board1 | 图页 | P1
绘制 | | 一拖四hub-1
审阅

V1.0 | A4 | 嘉立创EDA

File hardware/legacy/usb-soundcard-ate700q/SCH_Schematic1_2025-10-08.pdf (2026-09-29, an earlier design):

USB上行+HUB芯片 | USB下行

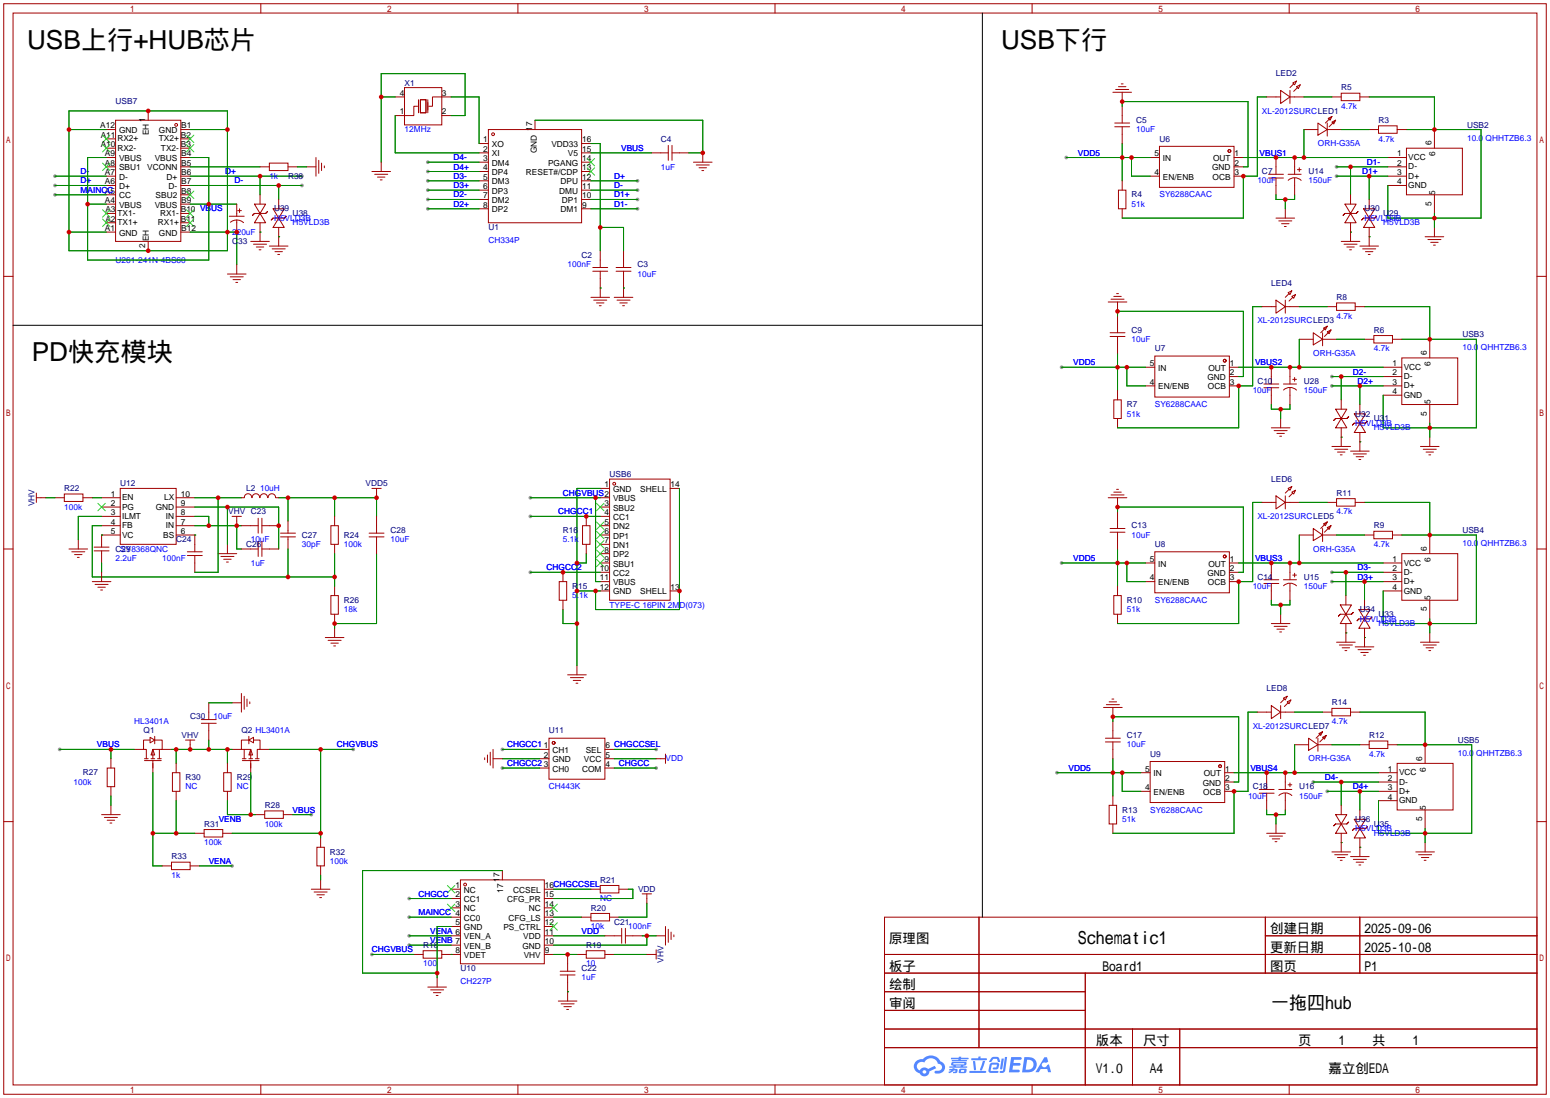
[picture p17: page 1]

GND 10 VDD 11 PS_CTRL 12 CFG_LS 13 NC 14 CFG_PR 15 CCSEL 16

原理图 | Schematic1 | 创建日期 | 2025-09-06

更新日期 | 2025-10-08

板子 | Board1 | 图页 | P1
绘制 | | 一拖四hub
审阅

V1.0 | A4 | 嘉立创EDA

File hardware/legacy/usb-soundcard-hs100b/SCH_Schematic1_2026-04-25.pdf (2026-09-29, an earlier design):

AVSS 25 VBIAS 26 VREF 27 MICIN 28 AVDD 29 LOL 30 LOBS 31 LOR 32 AVSS 33 AVDD 34 DVDD 35 DVSS 36 NC ³⁷

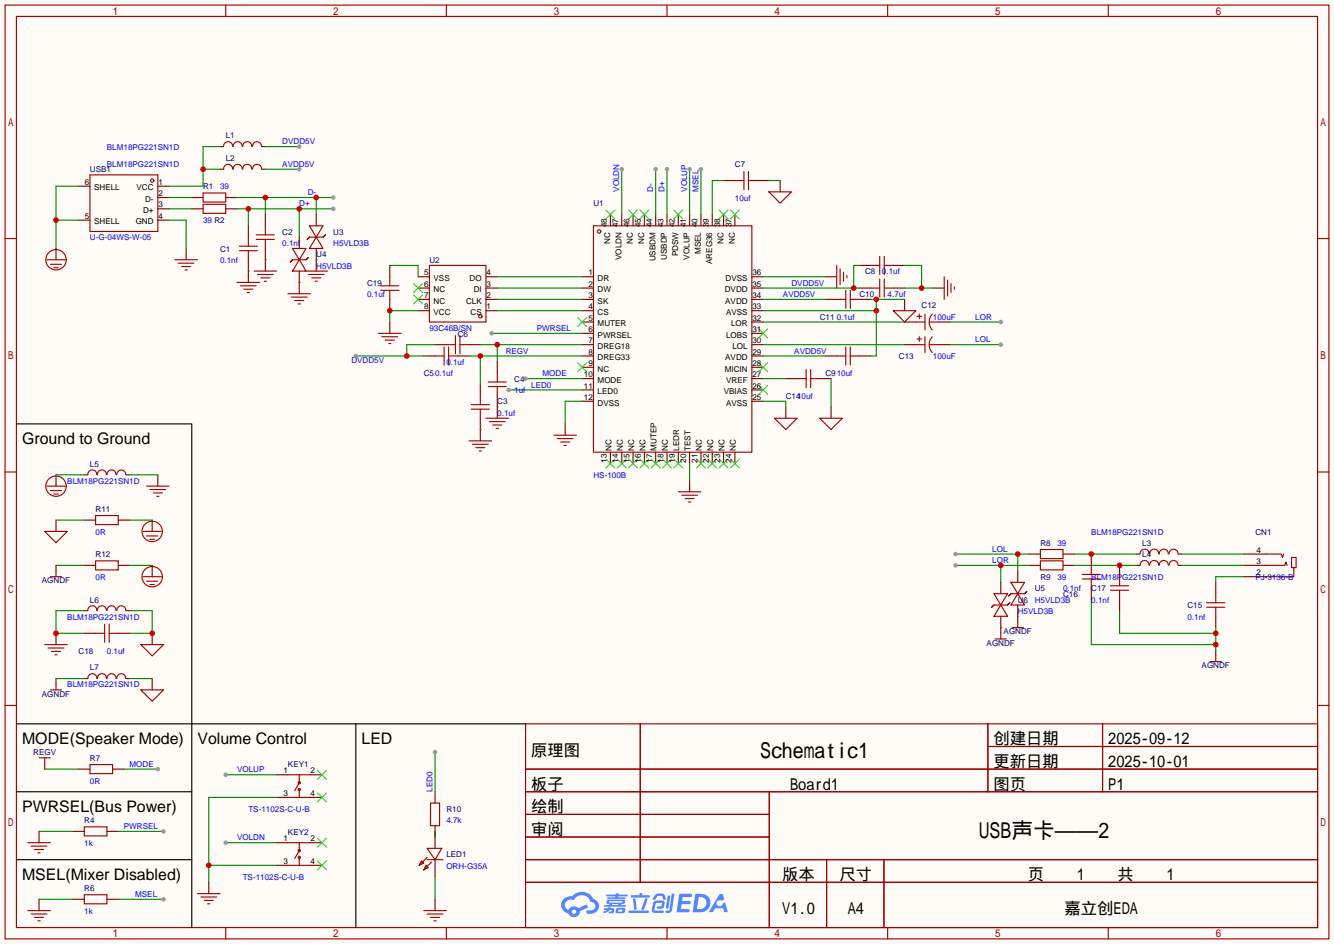
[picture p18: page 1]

更新日期 | 2025-10-01

板子 | Board1 | 图页 | P1
绘制 | | USB声卡——2
审阅

V1.0 | A4 | 嘉立创EDA

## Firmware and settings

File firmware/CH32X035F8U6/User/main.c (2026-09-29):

/********************************** (C) COPYRIGHT *******************************
 * File Name          : main.c
 * Author             : WCH
 * Version            : V1.0.0
 * Date               : 2023/12/26
 * Description        : Main program body.
*********************************************************************************
* Copyright (c) 2021 Nanjing Qinheng Microelectronics Co., Ltd.
* Attention: This software (modified or not) and binary are used for
* microcontroller manufactured by Nanjing Qinheng Microelectronics.
*******************************************************************************/

/*
 *@Note
 *GPIO routine:
 *PA0 push-pull output.
 *
 ***Only PA0--PA15 and PC16--PC17 support input pull-down.
 */

#include "debug.h"
#include "PD_Process.h"
#include "usbd_composite_km.h" // 引入 HID 头文件
#include "ch32x035_usbfs_device.h"

void TIM1_UP_IRQHandler(void) __attribute__((interrupt("WCH-Interrupt-fast")));

volatile UINT8  Tim_Ms_Cnt = 0x00;

void Switch_Init(void)
{
    GPIO_InitTypeDef GPIO_InitStructure = {0};
    RCC_APB2PeriphClockCmd(RCC_APB2Periph_GPIOB, ENABLE);

    GPIO_InitStructure.GPIO_Pin = GPIO_Pin_12;
    GPIO_InitStructure.GPIO_Mode = GPIO_Mode_Out_PP; // 推挽输出保证驱动电平稳定
    GPIO_InitStructure.GPIO_Speed = GPIO_Speed_50MHz;
    GPIO_Init(GPIOB, &GPIO_InitStructure);

    /* 默认输出低电平，初始化导通通道 1 (CC1) */
    GPIO_WriteBit(GPIOB, GPIO_Pin_12, Bit_RESET);
}

/*********************************************************************
 * @fn      TIM1_Init
 *
 * @brief   Initialize TIM1
 *
 * @return  none
 */
void TIM1_Init( u16 arr, u16 psc )
{
    TIM_TimeBaseInitTypeDef TIM_TimeBaseInitStructure={0};
    NVIC_InitTypeDef NVIC_InitStructure={0};
    RCC_APB2PeriphClockCmd( RCC_APB2Periph_TIM1, ENABLE );
    TIM_TimeBaseInitStructure.TIM_Period = arr;
    TIM_TimeBaseInitStructure.TIM_Prescaler = psc;
    TIM_TimeBaseInitStructure.TIM_ClockDivision = TIM_CKD_DIV1;
    TIM_TimeBaseInitStructure.TIM_CounterMode = TIM_CounterMode_Up;
    TIM_TimeBaseInitStructure.TIM_RepetitionCounter = 0x00;
    TIM_TimeBaseInit( TIM1, &TIM_TimeBaseInitStructure);
    TIM_ClearITPendingBit( TIM1, TIM_IT_Update );
    NVIC_InitStructure.NVIC_IRQChannel = TIM1_UP_IRQn;
    NVIC_InitStructure.NVIC_IRQChannelPreemptionPriority = 0;
    NVIC_InitStructure.NVIC_IRQChannelSubPriority = 3;
    NVIC_InitStructure.NVIC_IRQChannelCmd = ENABLE;
    NVIC_Init(&NVIC_InitStructure);
    TIM_ITConfig( TIM1, TIM_IT_Update, ENABLE );
    TIM_Cmd( TIM1, ENABLE );
}

#include "ch32x035.h"

/* 线控模拟全局变量 */
uint8_t  LineControl_Timer = 0;       // 模拟按键保持时间 (ms)
uint8_t  Current_Switch_State = 0;    // 当前模拟开关通道 (0:断开 1:播放 2:音量+ 3:音量-)

/*********************************************************************
 * @fn      EC11_Init
 * @brief   初始化旋转编码器引脚 (PB11, PB3, PB0)
 *********************************************************************/
void EC11_Init(void)
{
    GPIO_InitTypeDef GPIO_InitStructure = { 0 };
    RCC_APB2PeriphClockCmd(RCC_APB2Periph_GPIOB, ENABLE);

    /* A相(PB11), B相(PB3), 按键SW(PB0) 均配置为上拉输入 */
    GPIO_InitStructure.GPIO_Pin = GPIO_Pin_11 | GPIO_Pin_3 | GPIO_Pin_0;
    GPIO_InitStructure.GPIO_Mode = GPIO_Mode_IPU;
    GPIO_InitStructure.GPIO_Speed = GPIO_Speed_50MHz;
    GPIO_Init(GPIOB, &GPIO_InitStructure);
}

/*********************************************************************
 * @fn      Analog_Switch_Init
 * @brief   初始化 TS3A5017 控制引脚 (PA0=IN1, PA1=IN2)
 *********************************************************************/
void Analog_Switch_Init(void)
{
    GPIO_InitTypeDef GPIO_InitStructure = { 0 };
    RCC_APB2PeriphClockCmd(RCC_APB2Periph_GPIOA, ENABLE);

    /* 配置 PA0 和 PA1 为推挽输出 */
    GPIO_InitStructure.GPIO_Pin = GPIO_Pin_0 | GPIO_Pin_1;
    GPIO_InitStructure.GPIO_Mode = GPIO_Mode_Out_PP;
    GPIO_InitStructure.GPIO_Speed = GPIO_Speed_50MHz;
    GPIO_Init(GPIOA, &GPIO_InitStructure);

    /* 默认切到空闲通道 (IN2=0, IN1=0 对应的 NO1 必须物理悬空！) */
    GPIO_WriteBit(GPIOA, GPIO_Pin_1, Bit_RESET); // IN2
    GPIO_WriteBit(GPIOA, GPIO_Pin_0, Bit_RESET); // IN1
}

/*********************************************************************
 * @fn      TS3A5017_Select_Channel
 * @brief   控制模拟开关通道
 * @param   ch - 0:全断开, 1:播放/暂停, 2:音量+, 3:音量-
 *********************************************************************/
void TS3A5017_Select_Channel(uint8_t ch)
{
    /*
     * 真值表映射：PA1 控制 IN2，PA0 控制 IN1
     * 如果您的实际 PCB 电阻位置与此不同，请修改这里的 0/1 组合
     */
    switch(ch)
    {
        case 0: // 闲置/断开 (NO1 悬空)
            GPIO_WriteBit(GPIOA, GPIO_Pin_1, Bit_RESET); // IN2 = 0
            GPIO_WriteBit(GPIOA, GPIO_Pin_0, Bit_RESET); // IN1 = 0
            break;

        case 1: // 播放/暂停 (NO2 接 0 欧姆)
            GPIO_WriteBit(GPIOA, GPIO_Pin_1, Bit_RESET); // IN2 = 0
            GPIO_WriteBit(GPIOA, GPIO_Pin_0, Bit_SET);   // IN1 = 1
            break;

        case 2: // 音量 + (NO3 接 240 欧姆)
            GPIO_WriteBit(GPIOA, GPIO_Pin_1, Bit_SET);   // IN2 = 1
            GPIO_WriteBit(GPIOA, GPIO_Pin_0, Bit_RESET); // IN1 = 0
            break;

        case 3: // 音量 - (NO4 接 470 欧姆)
            GPIO_WriteBit(GPIOA, GPIO_Pin_1, Bit_SET);   // IN2 = 1
            GPIO_WriteBit(GPIOA, GPIO_Pin_0, Bit_SET);   // IN1 = 1
            break;
    }
}

/*********************************************************************
 * @fn      EC11_Process_1ms
 * @brief   带有缓冲队列的旋转编码器与线控模拟处理
 *********************************************************************/
void EC11_Process_1ms(void)
{
    /* 1. 读取引脚当前电平 */
    uint8_t pin_A  = GPIO_ReadInputDataBit(GPIOB, GPIO_Pin_11);
    uint8_t pin_B  = GPIO_ReadInputDataBit(GPIOB, GPIO_Pin_3);
    uint8_t pin_SW = GPIO_ReadInputDataBit(GPIOB, GPIO_Pin_0);

    static uint8_t last_A = 1;
    static int8_t  vol_queue = 0;     // 核心机制：音量脉冲队列（正数为加，负数为减）

    static uint8_t sw_debounce = 0;   // 中键防抖
    static uint8_t sw_pressed = 0;    // 中键状态

    static uint8_t pulse_state = 0;   // 发射状态机 (0:空闲, 1:按下导通, 2:松开断开)
    static uint8_t pulse_timer = 0;   // 状态维持时间

    /* --------- 1. 极速捕获旋转并压入队列 --------- */
    if (last_A == 1 && pin_A == 0)
    {
        if (pin_B == 1)
        {
            if (vol_queue < 20) vol_queue++; // 顺时针，加入队列
        }
        else
        {
            if (vol_queue > -20) vol_queue--; // 逆时针，加入队列
        }
    }
    last_A = pin_A; // 这里不再锁定定时器，允许极快连续旋转累加

    /* --------- 2. 中键按下的平滑消抖 --------- */
    if (pin_SW == 0) // 按下接地
    {
        if (sw_debounce < 20) sw_debounce++;
        if (sw_debounce == 15) sw_pressed = 1; // 稳定按下了 15ms
    }
    else
    {
        if (sw_debounce > 0) sw_debounce--;
        if (sw_debounce == 0) sw_pressed = 0;  // 彻底松开
    }

    /* --------- 3. 执行脉冲发射队列 --------- */
    if (sw_pressed)
    {
        // 物理中键优先级最高，直接霸占开关切到播放/暂停，打断音量队列
        TS3A5017_Select_Channel(1);
        pulse_state = 0; // 松开后，重新从空闲状态开始处理积累的音量
    }
    else
    {
        switch (pulse_state)
        {
            case 0: // 空闲状态：检查是否有待发送的音量脉冲
                if (vol_queue > 0)
                {
                    TS3A5017_Select_Channel(2); // 连通 240Ω
                    vol_queue--;                // 消耗一次记录
                    pulse_timer = 50;           // 导通维持 25ms
                    pulse_state = 1;
                }
                else if (vol_queue < 0)
                {
                    TS3A5017_Select_Channel(3); // 连通 470Ω
                    vol_queue++;                // 消耗一次记录
                    pulse_timer = 50;           // 导通维持 25ms
                    pulse_state = 1;
                }
                else
                {
                    TS3A5017_Select_Channel(0); // 队列清空，保持物理悬空
                }
                break;

            case 1: // 导通状态：欺骗声卡说“我按下了”
                if (pulse_timer > 0)
                {
                    pulse_timer--;
                }
                else
                {
                    TS3A5017_Select_Channel(0); // 必须切回全断开状态
                    pulse_timer = 40;           // 强制断开至少 25m
                    pulse_state = 2;
                }
                break;

            case 2: // 强制断开状态：给声卡反应时间，让它识别出“这是两次独立的点击”
                if (pulse_timer > 0)
                {
                    pulse_timer--;
                }
                else
                {
                    pulse_state = 0; // 冷却完毕，回到空闲，允许发射队列里的下一个脉冲
                }
                break;
        }
    }
}

/*********************************************************************
 * @fn      main
 *
 * @brief   Main program.
 *
 * @return  none
 */
int main(void)
{
    NVIC_PriorityGroupConfig(NVIC_PriorityGroup_1);
    SystemCoreClockUpdate();
    Delay_Init();

    /* 1. 初始化 CH443K 模拟开关控制引脚 */
    Switch_Init();

    /* 2. 初始化 PD 底层比较器 (内部会自动调用 PD_SINK_Init) */
    PD_Init();

    /* -------- 新增 HID 初始化 -------- */
    KB_Scan_Init();
    /* 初始化 USBFS 设备 (开启内部上拉，模拟设备插入) */
    USBFS_RCC_Init();
    USBFS_Device_Init( ENABLE , PWR_VDD_SupplyVoltage());
    USB_Sleep_Wakeup_CFG();
    Analog_Switch_Init();  // TS3A5017 输出引脚 (PA0, PA1)
    EC11_Init();           // 旋转编码器输入引脚 (PB11, PB3, PB0)
    /* 3. 启动定时器，系统主频设为 48MHz，这里分频后产生 1ms 中断 */
    TIM1_Init( 999, 48-1);

    while(1)
    {
        /* 获取定时器毫秒级时间差（关中断保证数据原子性） */
        TIM_ITConfig( TIM1, TIM_IT_Update , DISABLE );
        Tmr_Ms_Dlt = Tim_Ms_Cnt - Tmr_Ms_Cnt_Last;
        Tmr_Ms_Cnt_Last = Tim_Ms_Cnt;
        TIM_ITConfig( TIM1, TIM_IT_Update , ENABLE );

        PD_Ctl.Det_Timer += Tmr_Ms_Dlt;
        if(USBFS_DevEnumStatus)
        {
            if( USBFS_DevEnumStatus )
            {
                /* Handle keyboard scan data */
                KB_Scan_Handle();
            }
        }
        /* 定时轮询：每隔 5ms 唤醒一次底层 CC 电平检测 */
        if( PD_Ctl.Det_Timer > 4 )
        {
            PD_Ctl.Det_Timer = 0;

            /* 调用 PD_Process.c 中的核心检测防抖函数 */
            /* 该函数内部会自动处理手机插拔、CC 判定并直接翻转 PB12 */
            PD_Det_Proc();
        }

        /* 原版的 PD_Main_Proc() 巨型状态机已被彻底删除 */
    }
}


/*********************************************************************
 * @fn      TIM1_UP_IRQHandler
 *
 * @brief   This function handles TIM1 interrupt.
 *
 * @return  none
 */
void TIM1_UP_IRQHandler(void)
{
    if( TIM_GetITStatus( TIM1, TIM_IT_Update ) != RESET )
    {
        Tim_Ms_Cnt++;
        /* 每 1ms 扫描一次 PA4-PA7 键盘矩阵 */
        KB_Scan();
        EC11_Process_1ms(); // 新增的 EC11 与线控处理
        TIM_ClearITPendingBit( TIM1, TIM_IT_Update );
    }
}

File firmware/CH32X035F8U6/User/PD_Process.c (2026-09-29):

#include "debug.h"
#include "PD_Process.h"
#include "string.h"

/* 移除了所有 PD_Rx_Buf, PD_Tx_Buf, PDO_Len 等报文相关的变量 */

UINT8  Tmr_Ms_Cnt_Last;      /* 系统定时器毫秒计时上次值 */
UINT8  Tmr_Ms_Dlt;           /* 系统定时器毫秒计时本次间隔值 */
PD_CONTROL PD_Ctl;           /* PD 控制结构体 */

/*********************************************************************
 * @fn      PD_SINK_Init
 * @brief   初始化 SNK 检测模式 (注意：芯片外部必须自己挂 5.1k 下拉电阻)
 */
void PD_SINK_Init( void )
{
    PD_Ctl.Flag.Bit.PR_Role = 0;
    /* 配置 CC 引脚为比较器模式，用于检测手机端送来的 Rp 上拉电压 */
    USBPD->PORT_CC1 = CC_CMP_66 | CC_PD;
    USBPD->PORT_CC2 = CC_CMP_66 | CC_PD;
}

/*********************************************************************
 * @fn      PD_PHY_Reset
 * @brief   重置物理层状态
 */
void PD_PHY_Reset( void )
{
    PD_SINK_Init( );
    PD_Ctl.Flag.Bit.Stop_Det_Chk = 0;
    PD_Ctl.PD_State = STA_IDLE;
}

/*********************************************************************
 * @fn      PD_Init
 * @brief   初始化 PD 模块外设 (砍掉了 DMA 和 中断相关的配置)
 */
void PD_Init( void )
{
    GPIO_InitTypeDef GPIO_InitStructure = {0};
    RCC_APB2PeriphClockCmd(RCC_APB2Periph_GPIOC, ENABLE);
    RCC_APB2PeriphClockCmd(RCC_APB2Periph_AFIO, ENABLE);
    RCC_AHBPeriphClockCmd(RCC_AHBPeriph_USBPD, ENABLE);

    /* 配置 PC14(CC1) 和 PC15(CC2) 为浮空输入 */
    GPIO_InitStructure.GPIO_Pin = GPIO_Pin_14 | GPIO_Pin_15;
    GPIO_InitStructure.GPIO_Speed = GPIO_Speed_50MHz;
    GPIO_InitStructure.GPIO_Mode = GPIO_Mode_IN_FLOATING;
    GPIO_Init(GPIOC, &GPIO_InitStructure);

    AFIO->CTLR |= USBPD_IN_HVT | USBPD_PHY_V33;

    memset( &PD_Ctl.PD_State, 0x00, sizeof( PD_CONTROL ) );
    PD_PHY_Reset( );

    /* 注意：彻底移除了原版代码中开启接收中断的 PD_Rx_Mode() */
}

/*********************************************************************
 * @fn      PD_Detect
 * @brief   底层物理电平检测核心逻辑
 * @return  0:无连接; 1:CC1 正插; 2:CC2 反插
 */
UINT8 PD_Detect( void )
{
    UINT8  ret = 0;
    UINT8  cmp_cc1 = 0;
    UINT8  cmp_cc2 = 0;

    if(PD_Ctl.Flag.Bit.Connected)
    {
        /* 已经连接后，检测是否拔出。
         * 这里使用最符合 Type-C 规范且无需额外硬件走线的“CC 电压跌落法”。
         * 当手机（Source）拔出时，其端提供的 Rp 上拉电阻消失，
         * 此时 CC 线在板载 5.1k 下拉电阻的作用下，会瞬间跌回 0V。
         */
         USBPD->PORT_CC1 &= ~( CC_CMP_Mask | PA_CC_AI );
         USBPD->PORT_CC1 |= CC_CMP_22; // 切入 0.22V 比较器阈值
         Delay_Us(2);
         UINT8 cc1_is_high = (USBPD->PORT_CC1 & PA_CC_AI); // 只要大于0.22V就会返回非零值

         USBPD->PORT_CC2 &= ~( CC_CMP_Mask | PA_CC_AI );
         USBPD->PORT_CC2 |= CC_CMP_22;
         Delay_Us(2);
         UINT8 cc2_is_high = (USBPD->PORT_CC2 & PA_CC_AI);

         if( (cc1_is_high == 0) && (cc2_is_high == 0) )
         {
             /* 两个 CC 均低于 0.22V，判定为彻底拔出 */
             PD_Ctl.Flag.Bit.Connected = 0;
             ret = 0;
             printf("Device Disconnected\r\n");
          }
          else
          {
              /* 依然保持连接，回传当前维持高电平的通道 */
              if(cc1_is_high) { ret = 1; }
              else { ret = 2; }
           }
    }
    else
    {
        /* 检测插入状态：切入 0.22V 比较器阈值 */
        USBPD->PORT_CC1 &= ~( CC_CMP_Mask|PA_CC_AI );
        USBPD->PORT_CC1 |= CC_CMP_22;
        Delay_Us(2);
        if( USBPD->PORT_CC1 & PA_CC_AI ) { cmp_cc1 |= bCC_CMP_22; }

        USBPD->PORT_CC2 &= ~( CC_CMP_Mask|PA_CC_AI );
        USBPD->PORT_CC2 |= CC_CMP_22;
        Delay_Us(2);
        if( USBPD->PORT_CC2 & PA_CC_AI ) { cmp_cc2 |= bCC_CMP_22; }

        if (USBPD->PORT_CC1 & CC_PD)
        {
            if ((cmp_cc1 & bCC_CMP_22) == bCC_CMP_22) { ret = 1; }
            if ((cmp_cc2 & bCC_CMP_22) == bCC_CMP_22)
            {
                if( ret ) { ret = 1; } /* 应对某些带有双上拉的奇葩线材，默认优选 CC1 */
                else { ret = 2; }
            }
        }
    }
    return( ret );
}

/*********************************************************************
 * @fn      PD_Det_Proc
 * @brief   连接状态防抖与事件触发 (定时器中轮询调用)
 */
void PD_Det_Proc( void )
{
    UINT8  status;

    if( PD_Ctl.Flag.Bit.Connected )
    {
        /* 已连接状态的维护逻辑 */
    }
    else
    {
        status = PD_Detect( );

        if( status == 0 ) { PD_Ctl.Det_Cnt = 0; }
        else { PD_Ctl.Det_Cnt++; }

        /* 连续 5 次检测到相同的状态，确认插入 (防抖) */
                if( PD_Ctl.Det_Cnt >= 5 )
                {
                    PD_Ctl.Det_Cnt = 0;
                    PD_Ctl.Flag.Bit.Connected = 1;

                    if( status == 1 )
                    {
                        printf("Phone Connected: CC1 (正插)\r\n");
                        /* PB12 输出低电平 (0)，控制 CH443K 导通通道 1 */
                        GPIO_WriteBit(GPIOB, GPIO_Pin_12, Bit_RESET);
                    }
                    else if( status == 2 )
                    {
                        printf("Phone Connected: CC2 (反插)\r\n");
                        /* PB12 输出高电平 (1)，控制 CH443K 导通通道 2 */
                        GPIO_WriteBit(GPIOB, GPIO_Pin_12, Bit_SET);
                    }
                }
    }
}

/*********************************************************************
 * @fn      PD_Main_Proc
 * @brief   原版的巨型状态机，现在可以直接留空，或者处理简单的用户逻辑
 */
void PD_Main_Proc( )
{
    /* 所有的 PD 握手状态机已删除，主循环仅需维持计时器给 PD_Det_Proc 即可 */
}
